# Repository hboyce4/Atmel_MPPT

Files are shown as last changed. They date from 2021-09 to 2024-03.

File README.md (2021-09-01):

# Atmel_MPPT
A Maximum Power Point Tracker converter for solar panels, running on an Atmel 8-bit MCU

Possible improvements to be made:
- Add load switch to cut power to the USB port when the battery is too low and prevent overdischarge/BMS cutout.
- Update to a 32-bit MCU.
- Change the AP3513 switching regulator IC for one with a smaller quiescent current.

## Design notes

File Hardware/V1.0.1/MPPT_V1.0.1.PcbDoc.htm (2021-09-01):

Reporting Options

# File in Previous Format

Date | : | 2021-09-01
Time | : | 19:13:26
Filename | : | C:\Users\Hugo Boyce\Documents\Electronics Projects\MPPT\Git\Atmel_MPPT\Hardware\V1.0.1\MPPT_V1.0.1.PcbDoc

Version | Warning

This file was generated by an earlier version of the software

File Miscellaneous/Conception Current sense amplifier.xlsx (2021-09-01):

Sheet: PV_Current
 |  |  |  | Editable fields in gray
Design Parameters
Vref | 4.096 | V | Max shunt voltage | 0 | V
Steps | 1024 | LSB | Min shunt voltage | -0.0512 | V
Imax | 0 | A | Peak shunt power | 0.0262144 | W
Imin | -0.512 | A |  | 26.2144 | mW
Rshunt | 0.1 | Ohms | R2/R1 | 80
 | 100 | mOhms
 |  |  | R1/(R2+R1) | 0.01234567901
 |  |  | Vref | 0 | V
 |  |  |  | 0 | mV
Composants choisis: |  |  | R1/(R2+R1), Vref | 0
R1 gain: | 1500 |  | Theoratical Formula
R2 gain: | 120000 |  |  |  |  | Formule théorique: | mA = (BIN - | 0 | ) * | 0.5
real R2/R1 | 80
R1 vref: | 1000
R2 vref: | 200000
real Vref: | 0 | V | Total range | 0.512 | A
 |  |  |  | 0.5 | mA/LSB
real max sh. V | 0 | V | Vadc @ 0A | 0 | V
real min sh. V | -0.0512 | V | LSB @ 0A | 0 | LSB
real Imax | 0 | A
real Imin | -0.512 | A | Real Formula
 |  |  | Range réel | 0.512 | A
 |  |  |  | 0.5 | mA/LSB
Low Pass Filter
Fc | 1185 | Hz | Vdc @ 0A | 0 | V
 |  |  | LSB @ 0A | 0 | LSB
C | 8.841941283e-08 | F |  |  |  | Formule théorique: | mA = (BIN - | 0 | ) * | 0.5
 | 0.08841941283 | uF
 | 88.41941283 | nF
 | 88419.41283 | pF

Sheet: Batt_Current
 |  |  |  | Editable fields in gray
Design Parameters
Vref | 4.096 | V | Max shunt voltage | 0.02048 | V
Steps | 1024 | LSB | Min shunt voltage | -0.06144 | V
Imax | 1.024 | A | Peak shunt power | 0.18874368 | W
Imin | -3.072 | A |  | 188.74368 | mW
Rshunt | 0.02 | Ohms | R2/R1 | 50
 | 20 | mOhms
 |  |  | R1/(R2+R1) | 0.01960784314
 |  |  | Vref | 0.02007843137 | V
 |  |  |  | 20.07843137 | mV
Composants choisis: |  |  | R1/(R2+R1), Vref | 0.004901960784
R1 gain: | 2000 |  | Theoratical Formula
R2 gain: | 100000 |  |  |  |  | Formule théorique: | mA = (BIN - | 256 | ) * | 4
real R2/R1 | 50
R1 vref: | 1000
R2 vref: | 200000
real Vref: | 0.02037810945 | V | Total range | 4.096 | A
 |  |  |  | 4 | mA/LSB
real max sh. V | 0.02078567164 | V | Vadc @ 0A | 1.024 | V
real min sh. V | -0.06113432836 | V | LSB @ 0A | 256 | LSB
real Imax | 1.039283582 | A
real Imin | -3.056716418 | A | Real Formula
 |  |  | Range réel | 4.096 | A
 |  |  |  | 4 | mA/LSB
Low Pass Filter
Fc | 1185 | Hz | Vdc @ 0A | 1.039283582 | V
 |  |  | LSB @ 0A | 259.8208955 | LSB
C | 6.581090474e-08 | F |  |  |  | Formule théorique: | mA = (BIN - | 260 | ) * | 4
 | 0.06581090474 | uF
 | 65.81090474 | nF
 | 65810.90474 | pF

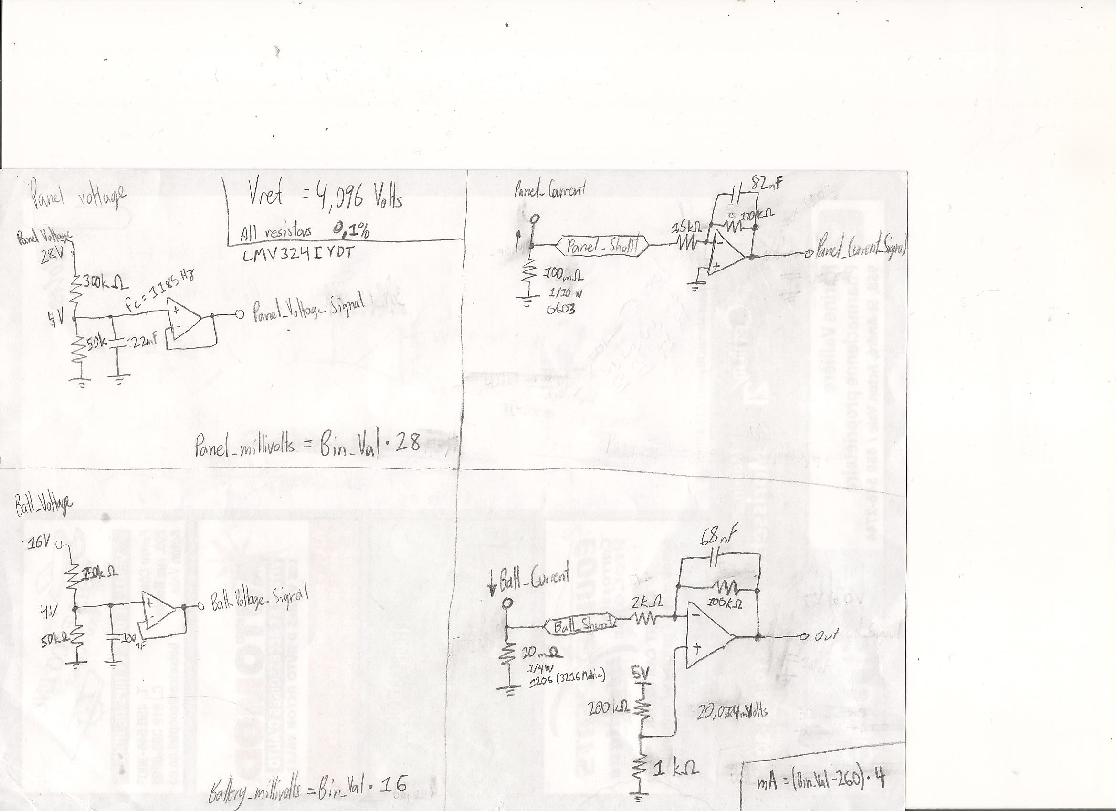
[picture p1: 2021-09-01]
Miscellaneous/MPPT_V1.0_Sense_Amplifiers.jpeg

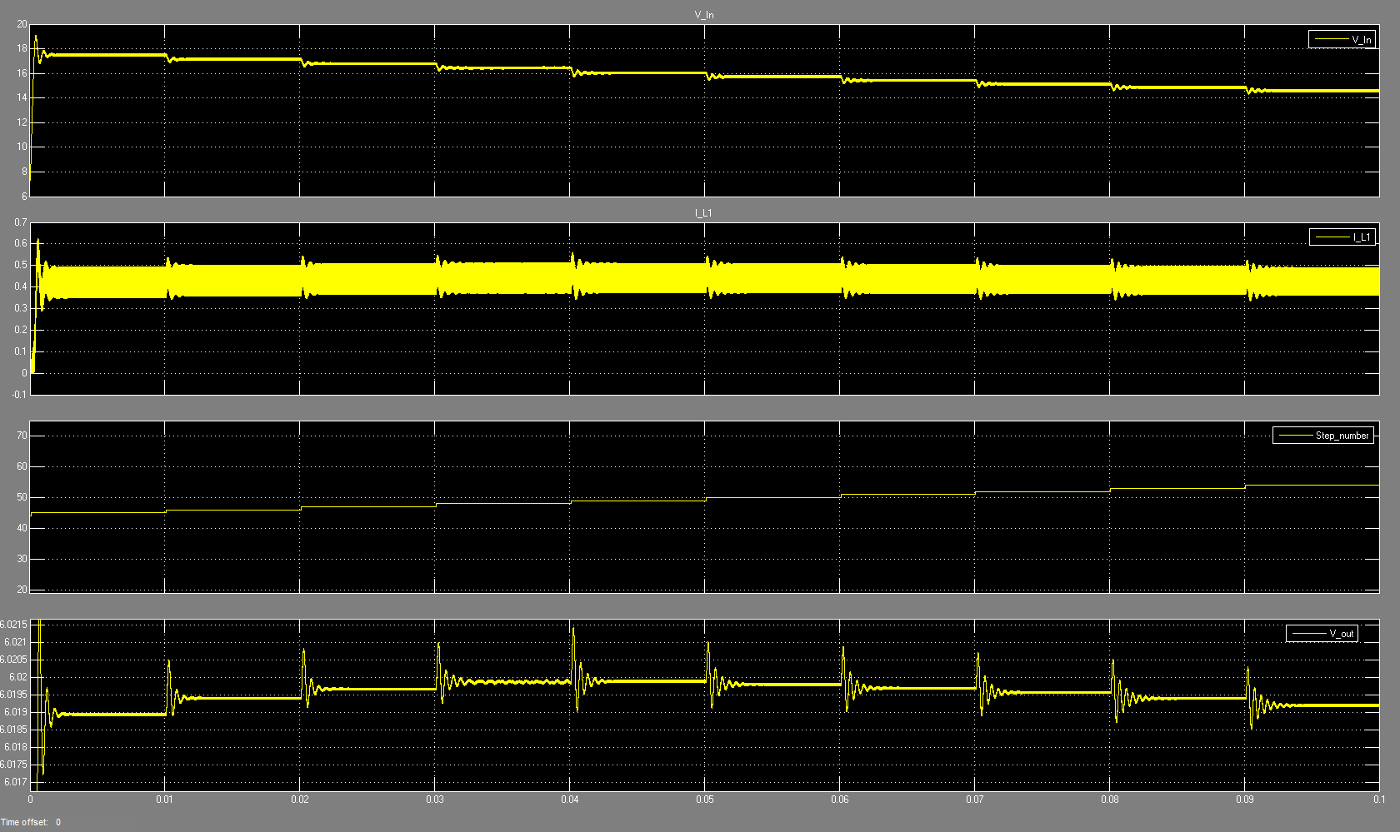
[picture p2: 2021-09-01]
Simulation/Sim Hacheur/Captures/Point optimal puissance.PNG

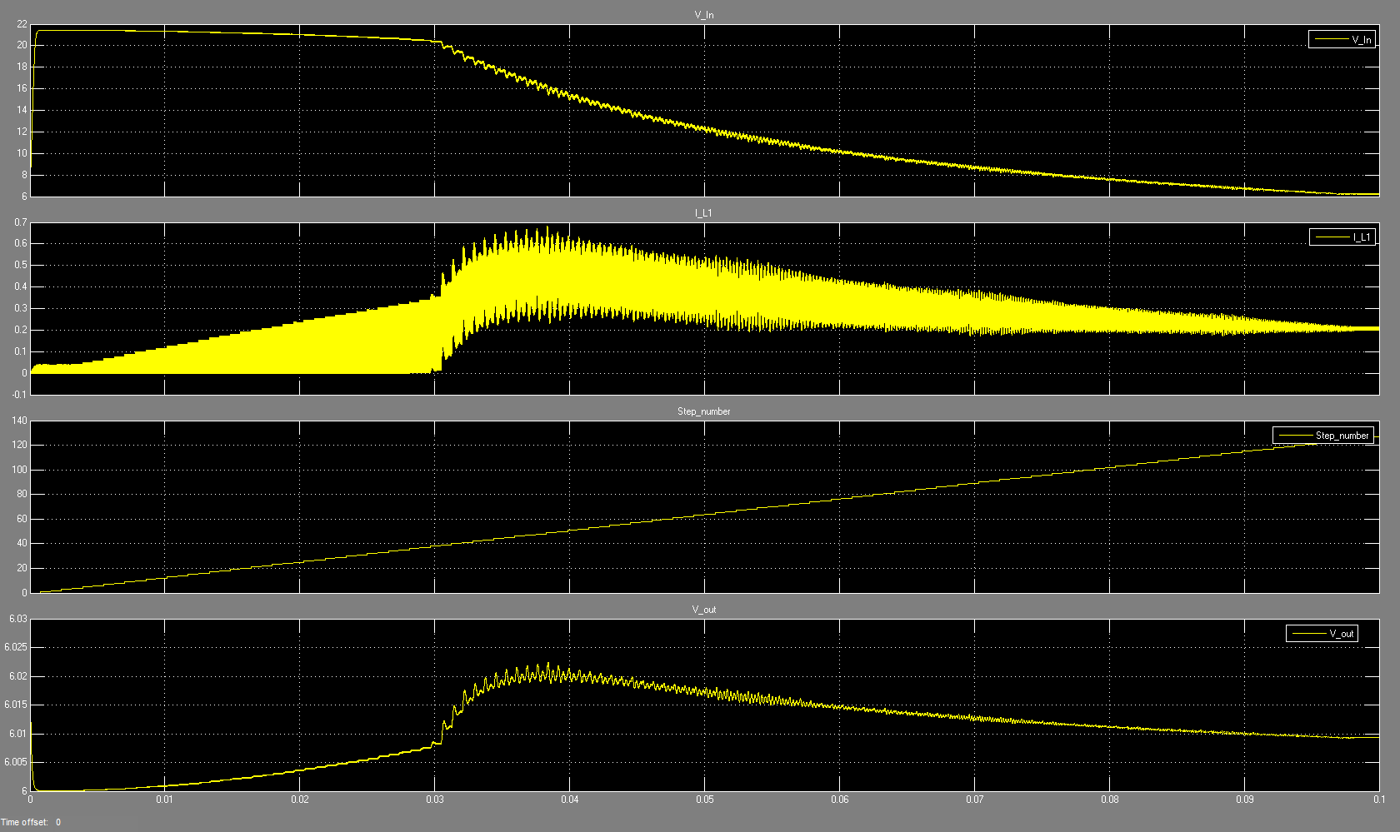
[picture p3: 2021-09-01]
Simulation/Sim Hacheur/Captures/100uH.PNG

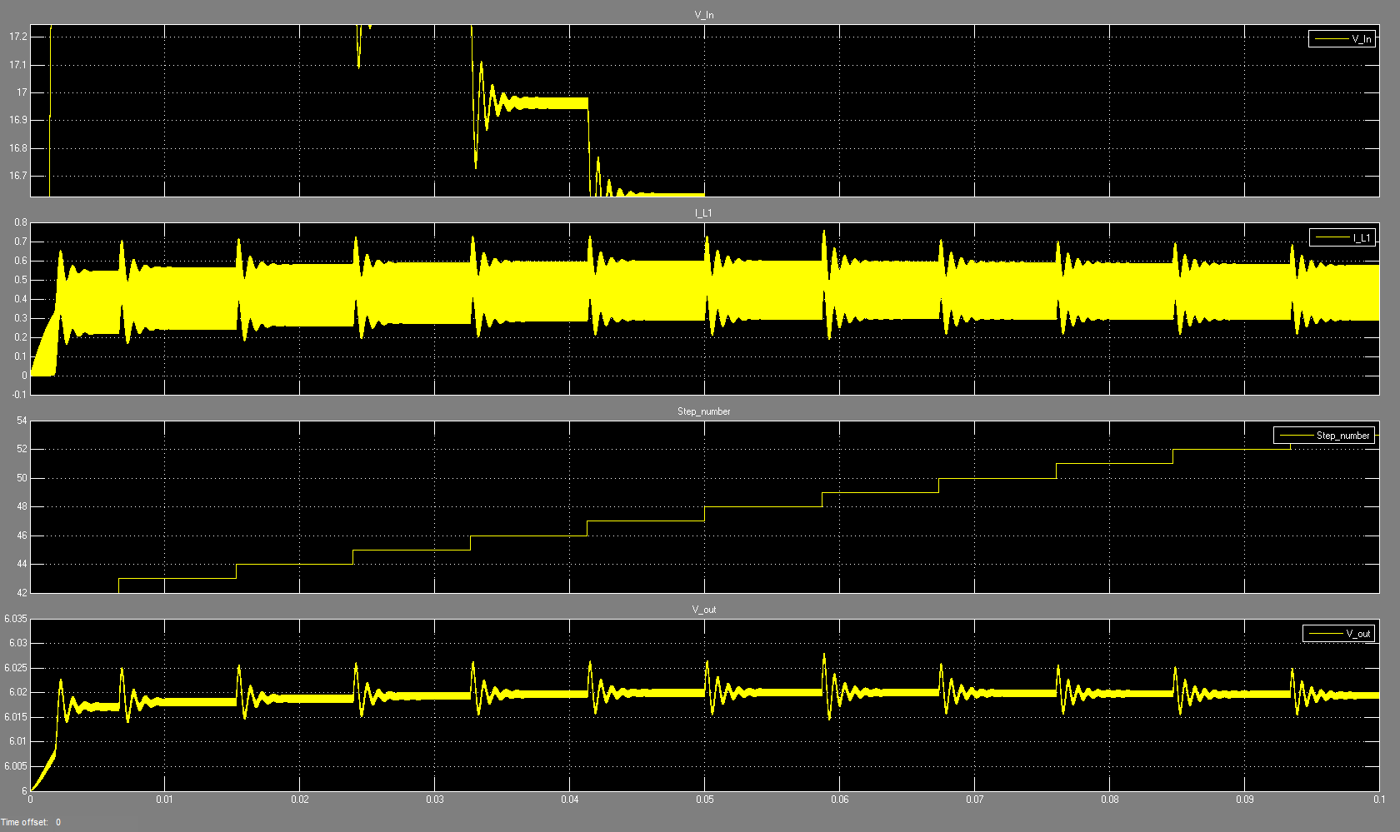
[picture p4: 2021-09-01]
Simulation/Sim Hacheur/Captures/HAcheur, 100uH, 22uF, 220uF.PNG

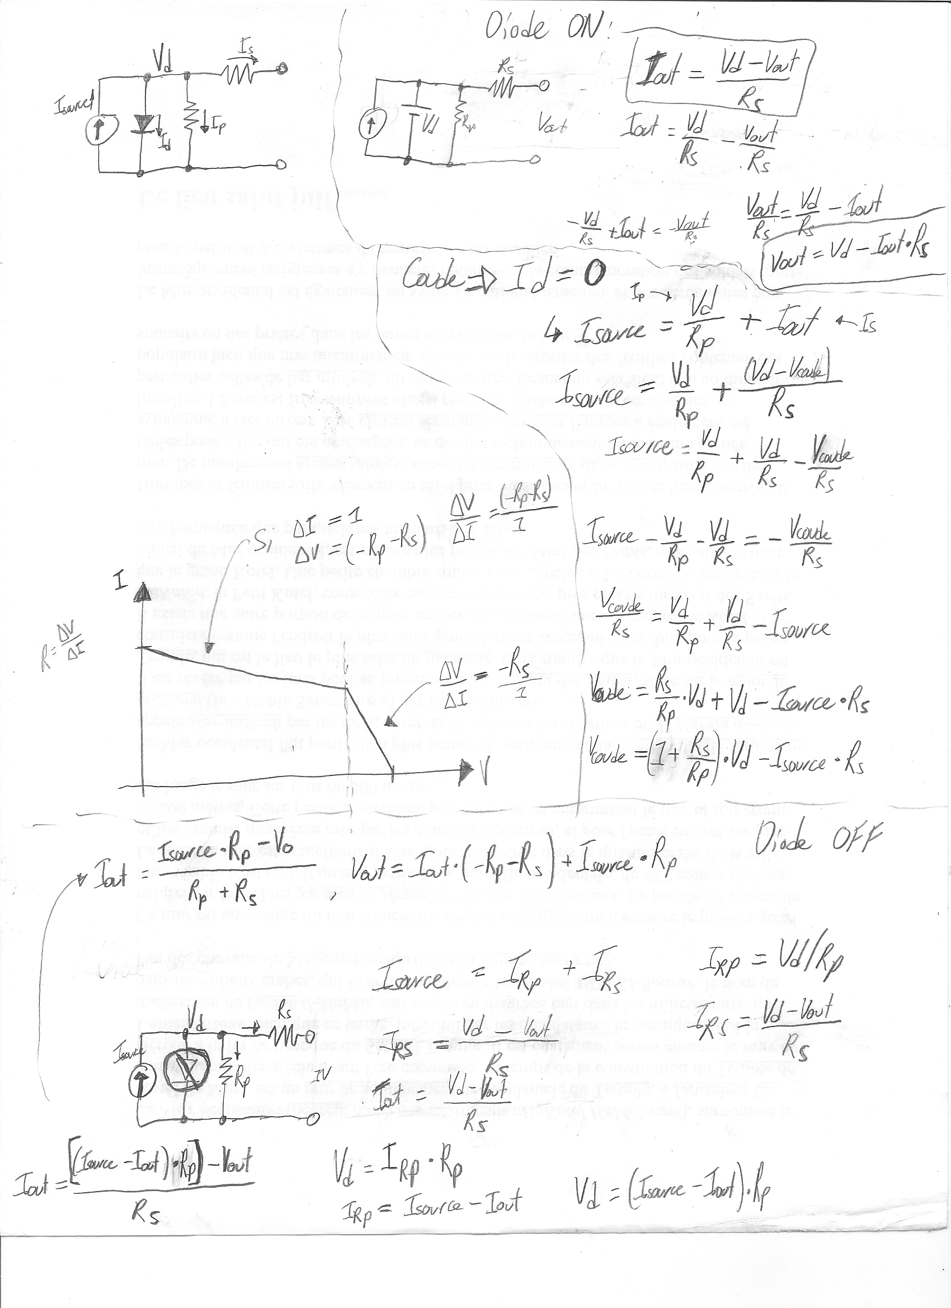
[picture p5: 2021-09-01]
Miscellaneous/Approx linéaires PV cell 001.bmp

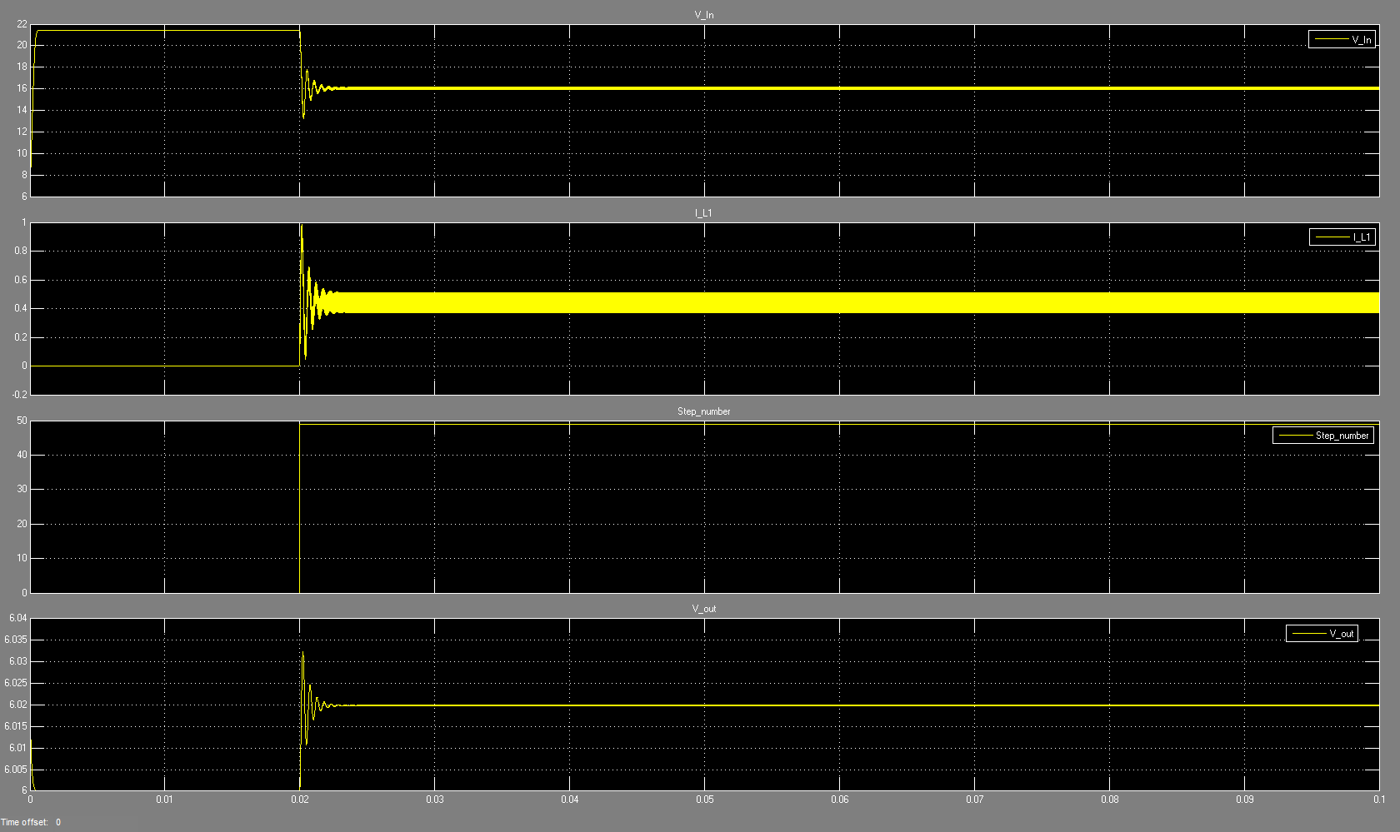
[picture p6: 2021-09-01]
Simulation/Sim Hacheur/Captures/Temps stabilisation, no-power to max power.PNG

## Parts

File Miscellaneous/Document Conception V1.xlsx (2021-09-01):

BOM
Digikey P/N | Manuf. P/N | Comment | Qty | URL
AP3513EMPTR-G1DICT-ND | AP3513EMPTR-G1 | Buck converter IC | 1 | http://www.digikey.ca/product-detail/en/diodes-incorporated/AP3513EMPTR-G1/AP3513EMPTR-G1DICT-ND/4505181
RLB0912-4R7ML-ND | RLB0912-4R7ML | Inductor | 1 | http://www.digikey.ca/products/en/inductors-coils-chokes/fixed-inductors/71?k=RLB0912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
 | AIAP-03-101 | Inductor | 1
 | BUK9M53-60E | N_mosfet | 1
732-8602-1-ND (https://www.digikey.ca/product-detail/en/wurth-electronics-inc/860010373010/732-8602-1-ND/5728559) | 860010373010 (https://www.digikey.ca/product-detail/en/wurth-electronics-inc/860010373010/732-8602-1-ND/5728559) | 220uF electrolytic cap | 1 | https://www.digikey.ca/product-detail/en/wurth-electronics-inc/860010373010/732-8602-1-ND/5728559
 | ATMEGA16A-AU | Microcontrôleur Atmel | 1
497-4943-1-ND (https://www.digikey.ca/product-detail/en/stmicroelectronics/LMV324IDT/497-4943-1-ND/1003414) | LMV324IDT (https://www.digikey.ca/product-detail/en/stmicroelectronics/LMV324LIDT/497-13052-1-ND/3458219) | Quad rail-to-rail op amp | 1 | https://www.digikey.ca/product-detail/en/stmicroelectronics/LMV324IDT/497-4943-1-ND/1003414
ISL6208CBZ-ND (https://www.digikey.ca/product-detail/en/intersil/ISL6208CBZ/ISL6208CBZ-ND/1063886) | ISL6208CBZ (https://www.digikey.ca/product-detail/en/intersil/ISL6208CBZ/ISL6208CBZ-ND/1063886) | Mosfet driver IC | 1 | https://www.digikey.ca/product-detail/en/intersil/ISL6208CBZ/ISL6208CBZ-ND/1063886

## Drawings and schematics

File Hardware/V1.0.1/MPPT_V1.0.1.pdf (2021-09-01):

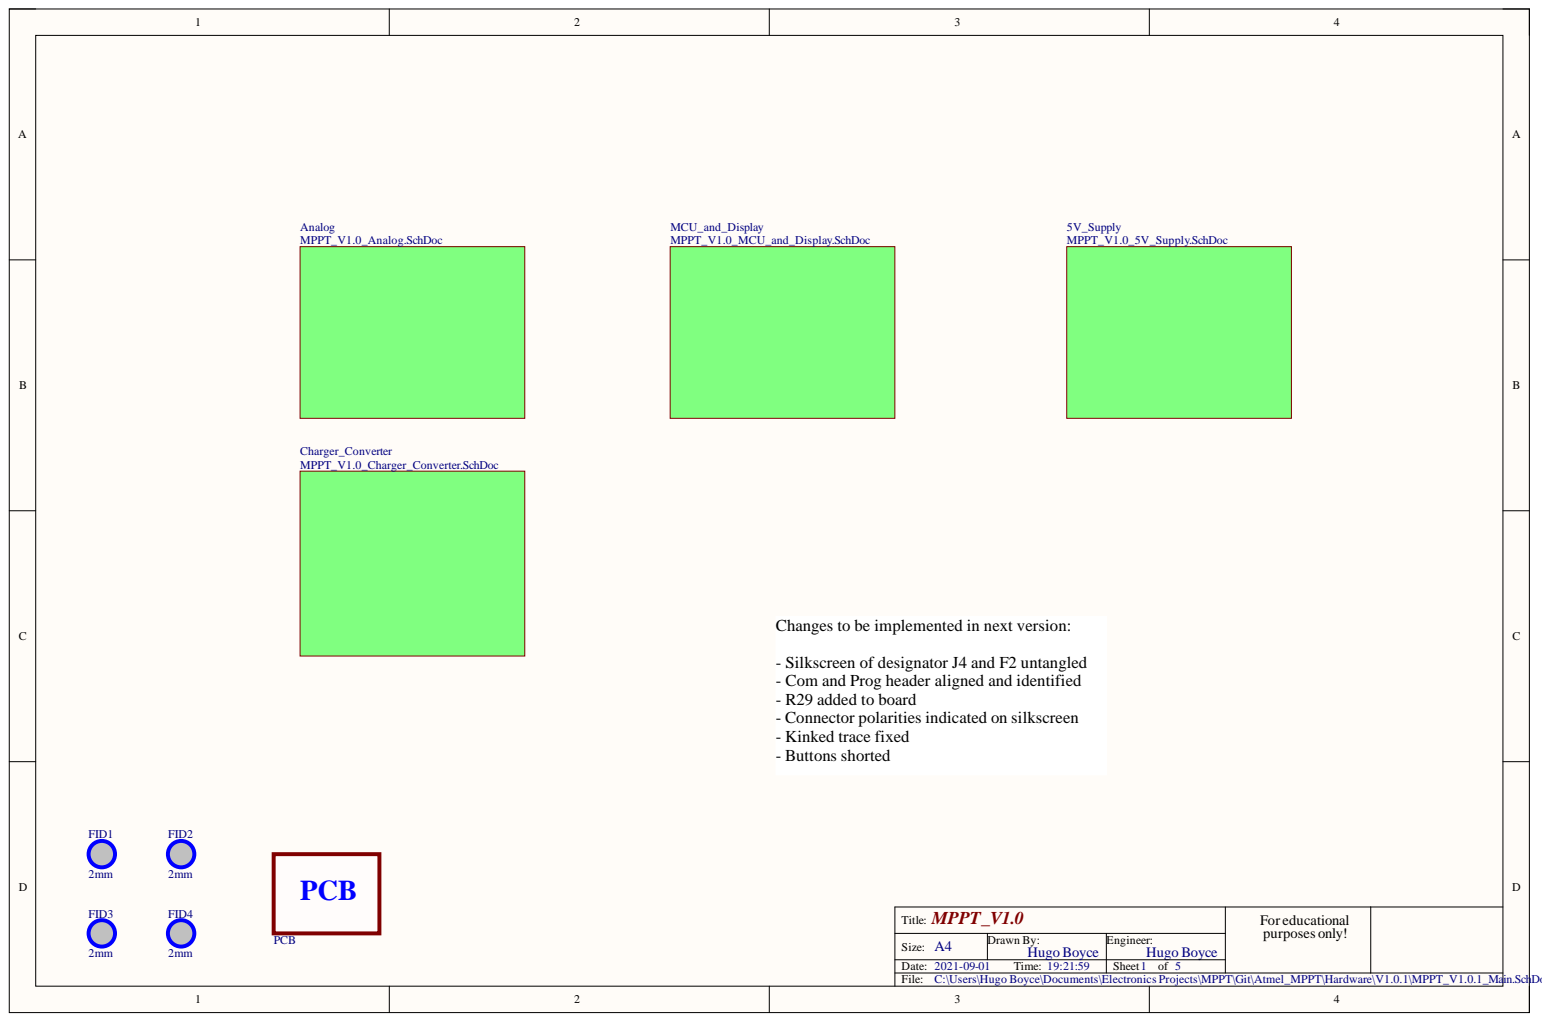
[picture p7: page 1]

Changes to be implemented in next version:

- Silkscreen of designator J4 and F2 untangled
- Com and Prog header aligned and identified
- R29 added to board
- Connector polarities indicated on silkscreen
- Kinked trace fixed
- Buttons shorted

MPPT_V1.0
Title:
Date:
C:\Users\Hugo Boyce\Documents\Electronics Projects\MPPT\Git\Atmel_MPPT\Hardware\V1.0.1\MPPT_V1.0.1_Main.SchDoc

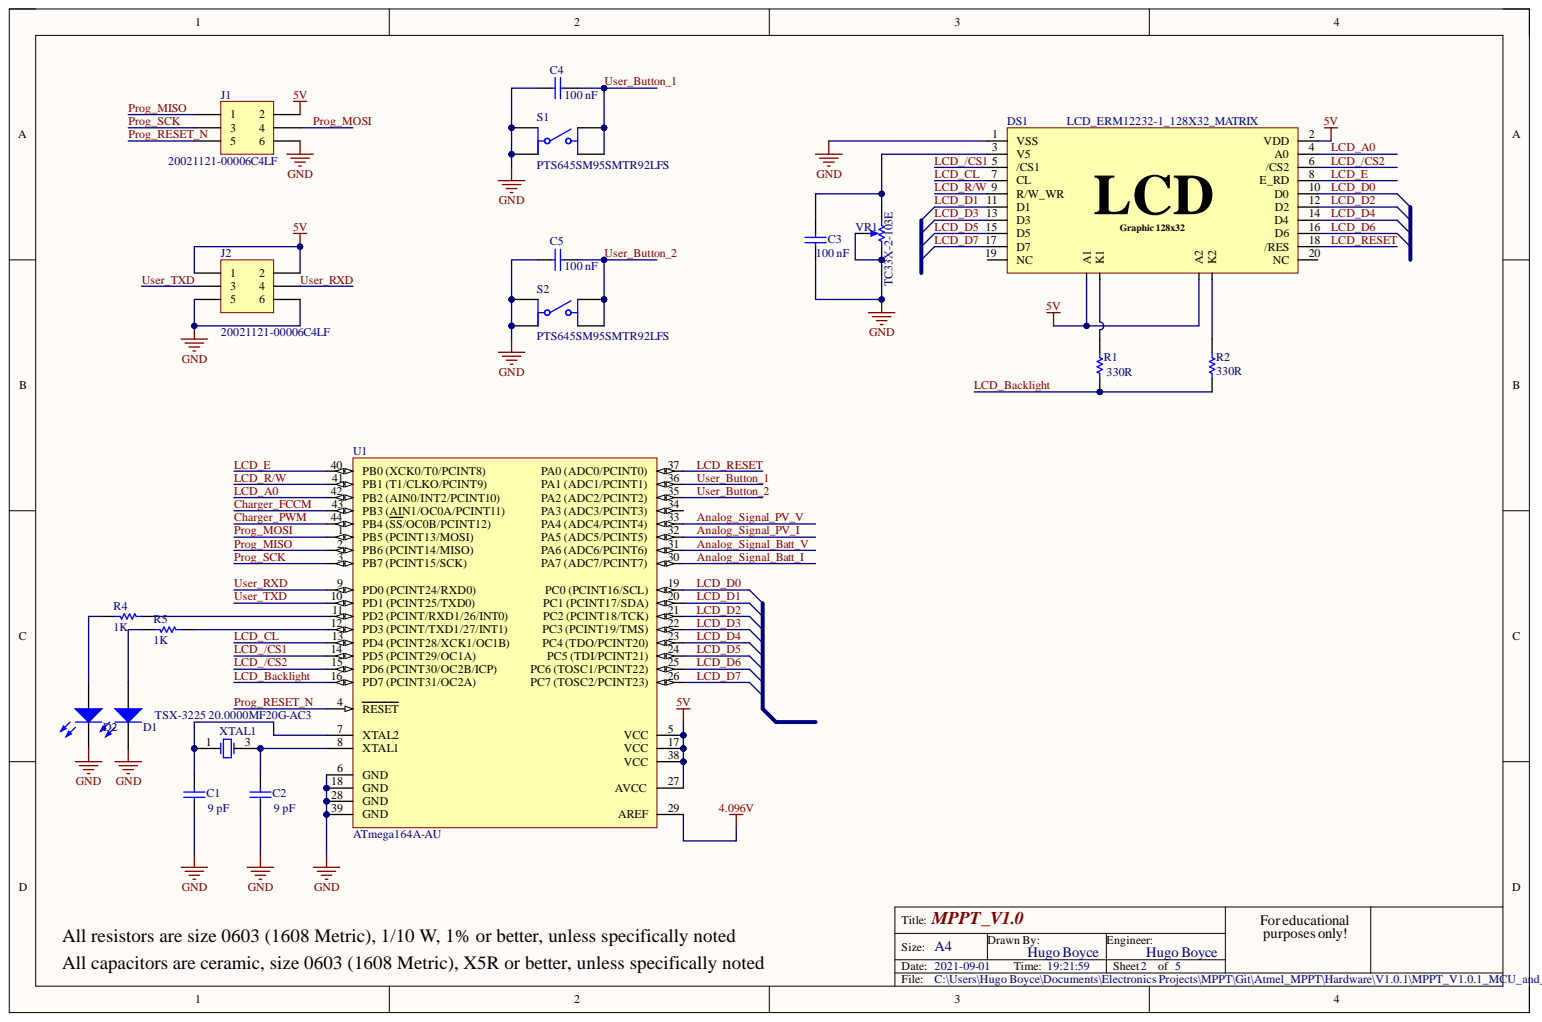
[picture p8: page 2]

All resistors are size 0
All capacitors are ceramic, size 0

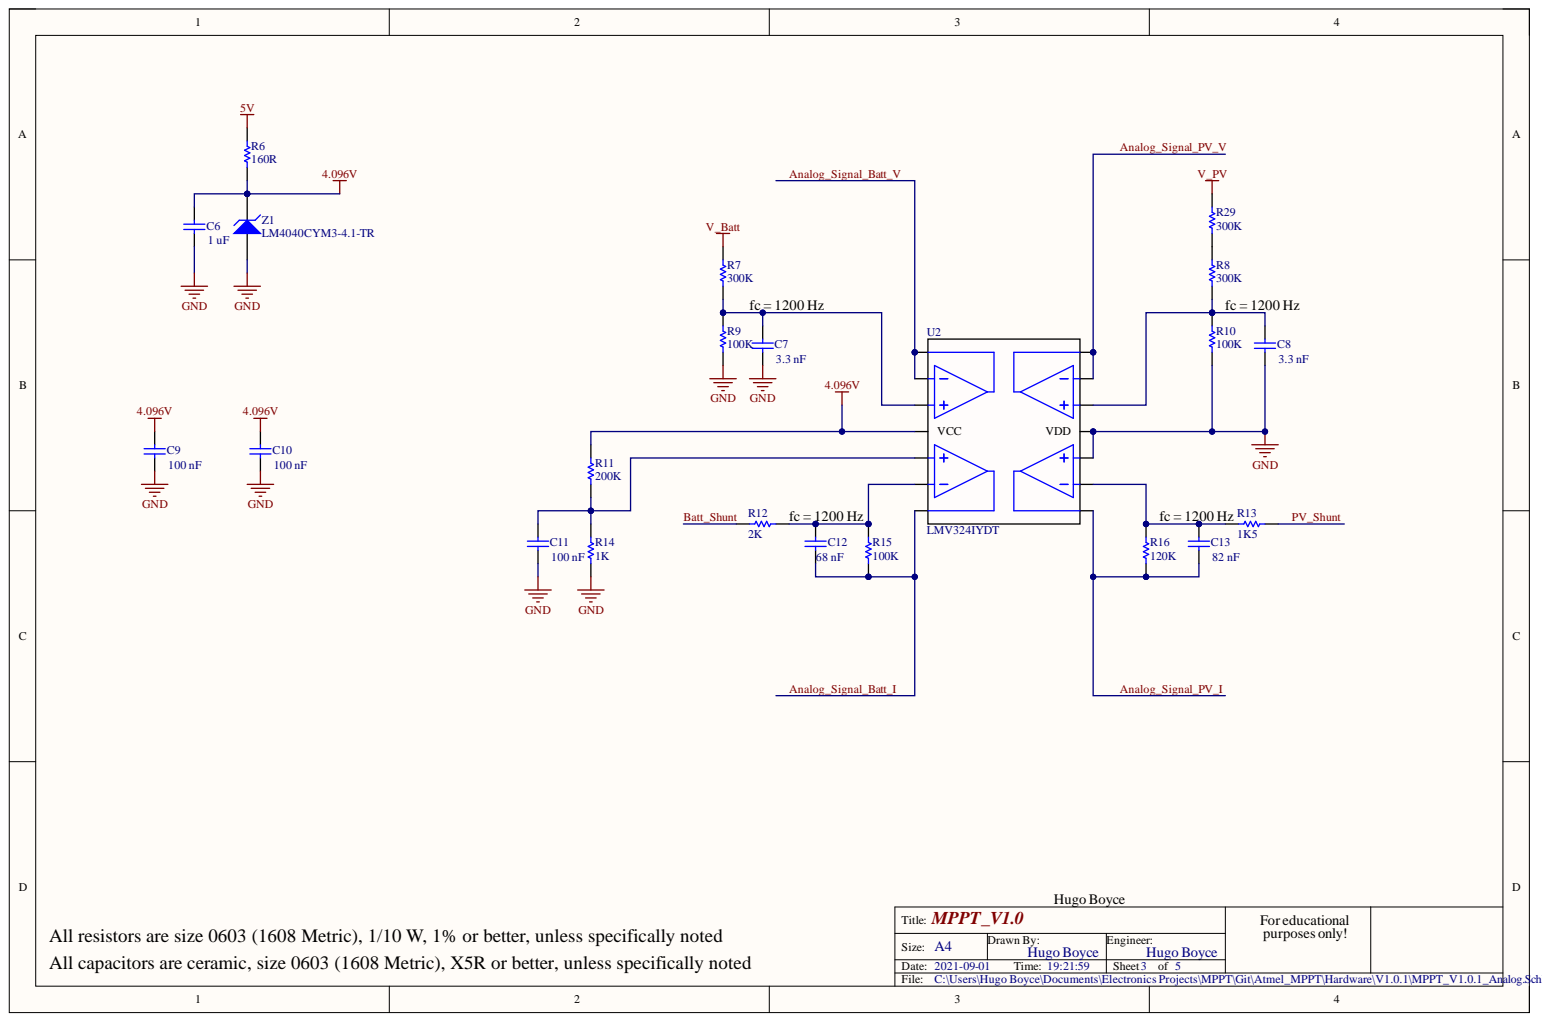
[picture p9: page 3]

All resistors are size 0
All capacitors are ceramic, size 0

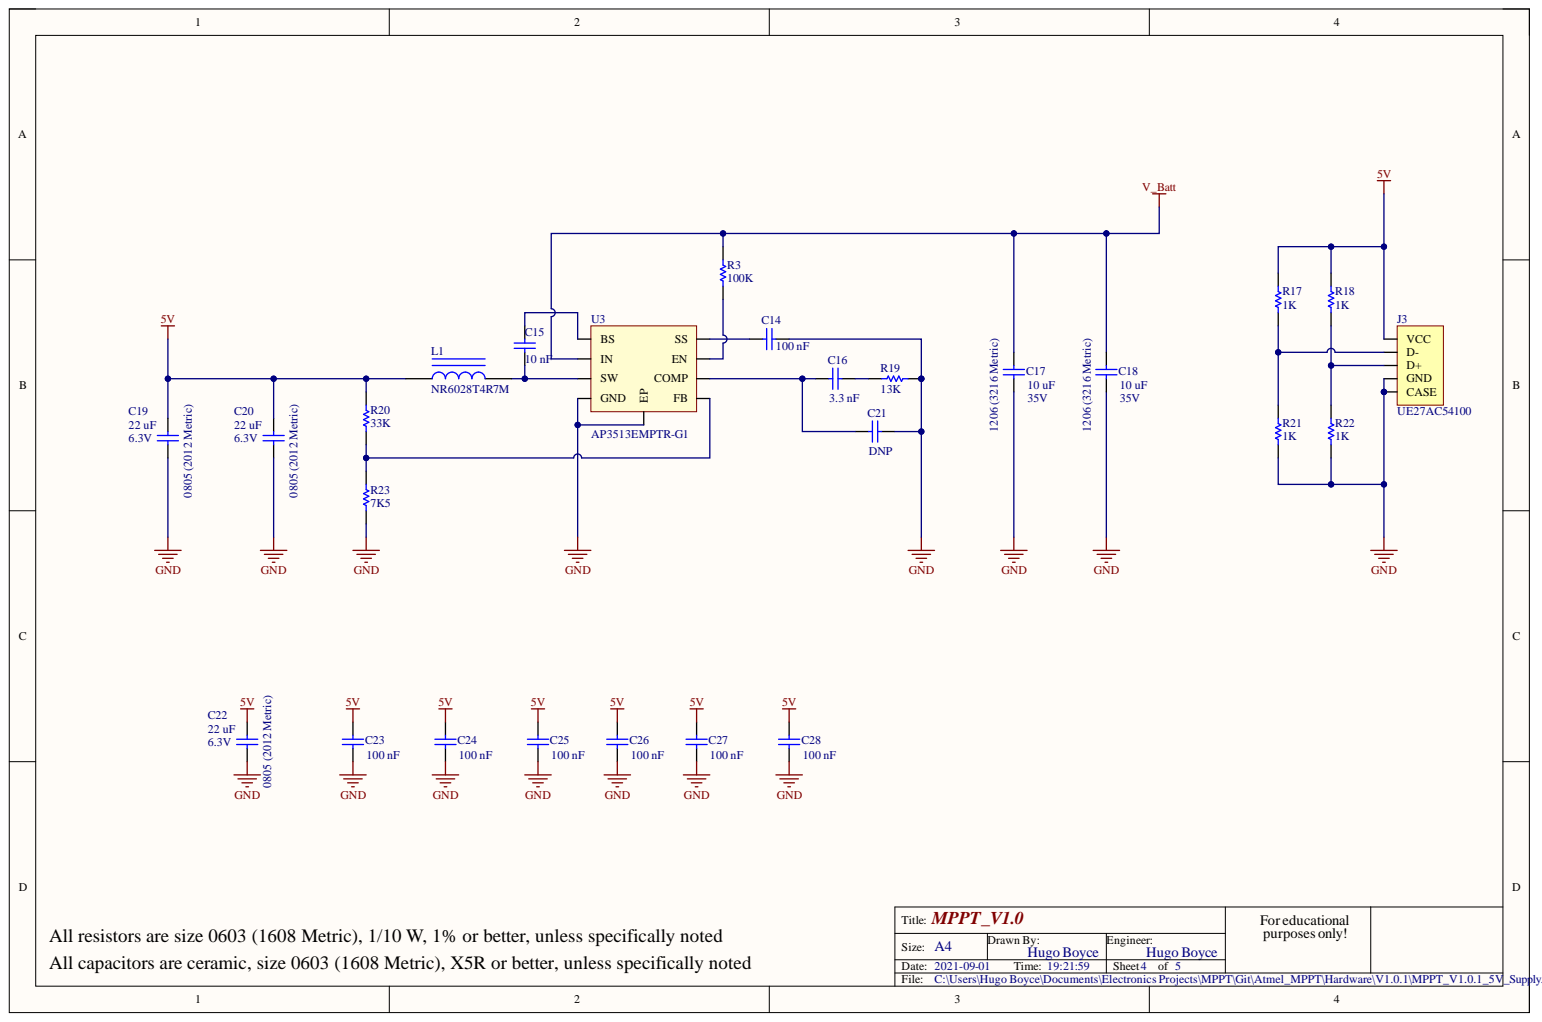
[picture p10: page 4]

IN COMP EN SWGND FB | C1 6

All resistors are size 0
All capacitors are ceramic, size 0

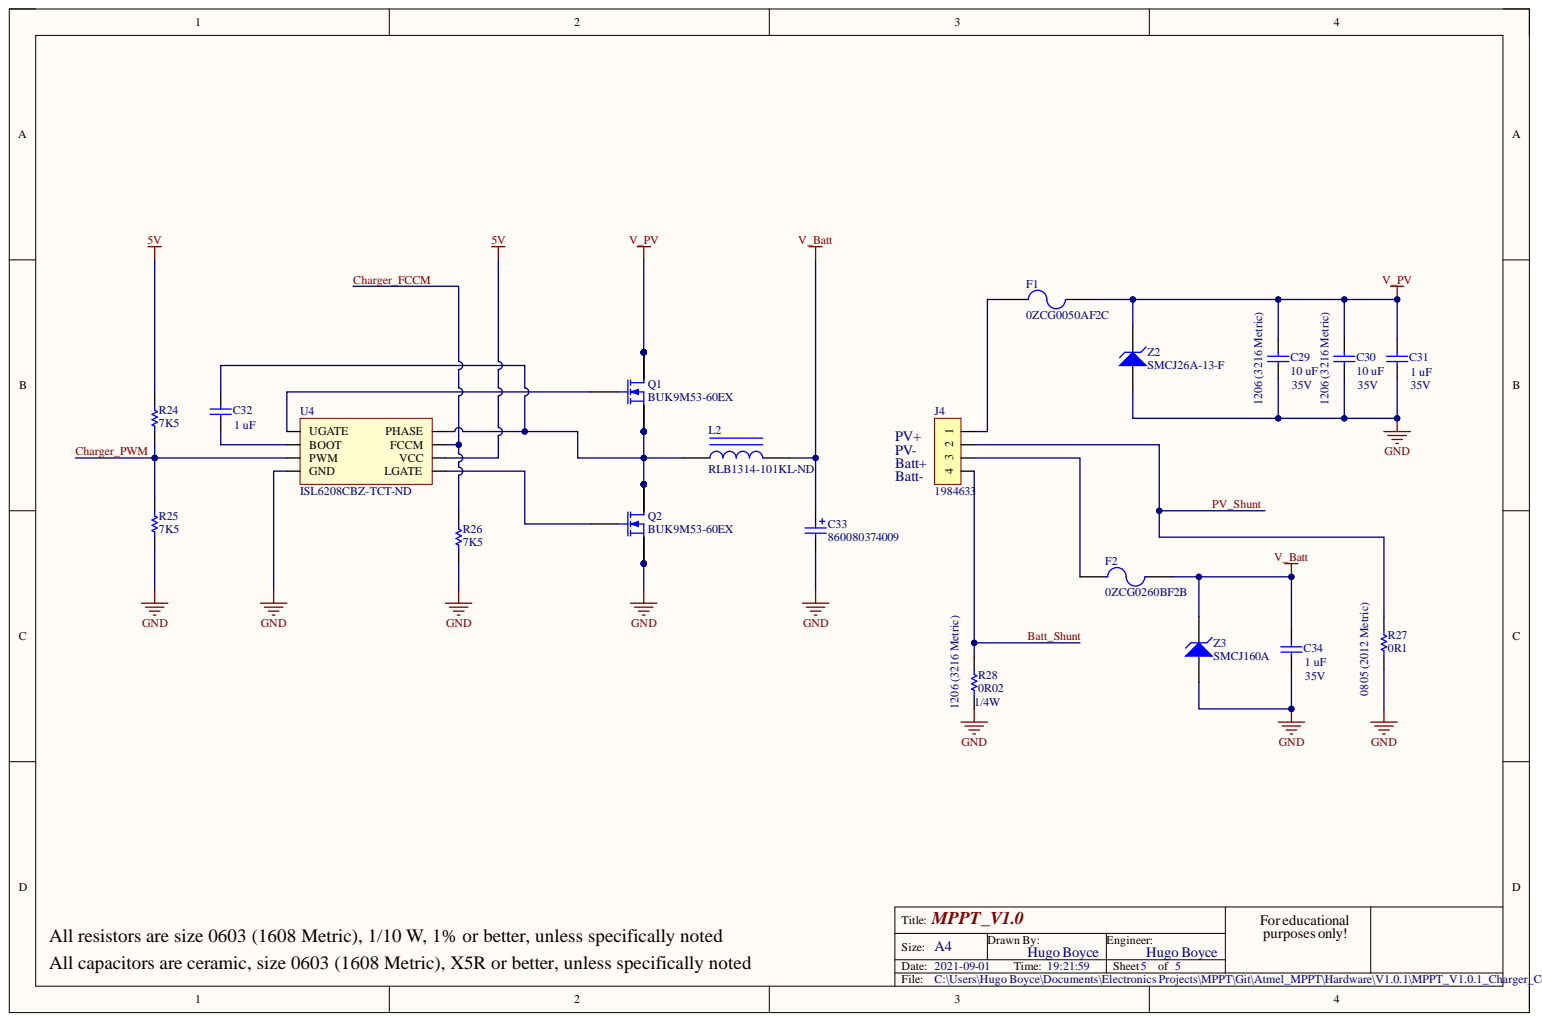
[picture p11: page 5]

All resistors are size 0
All capacitors are ceramic, size 0

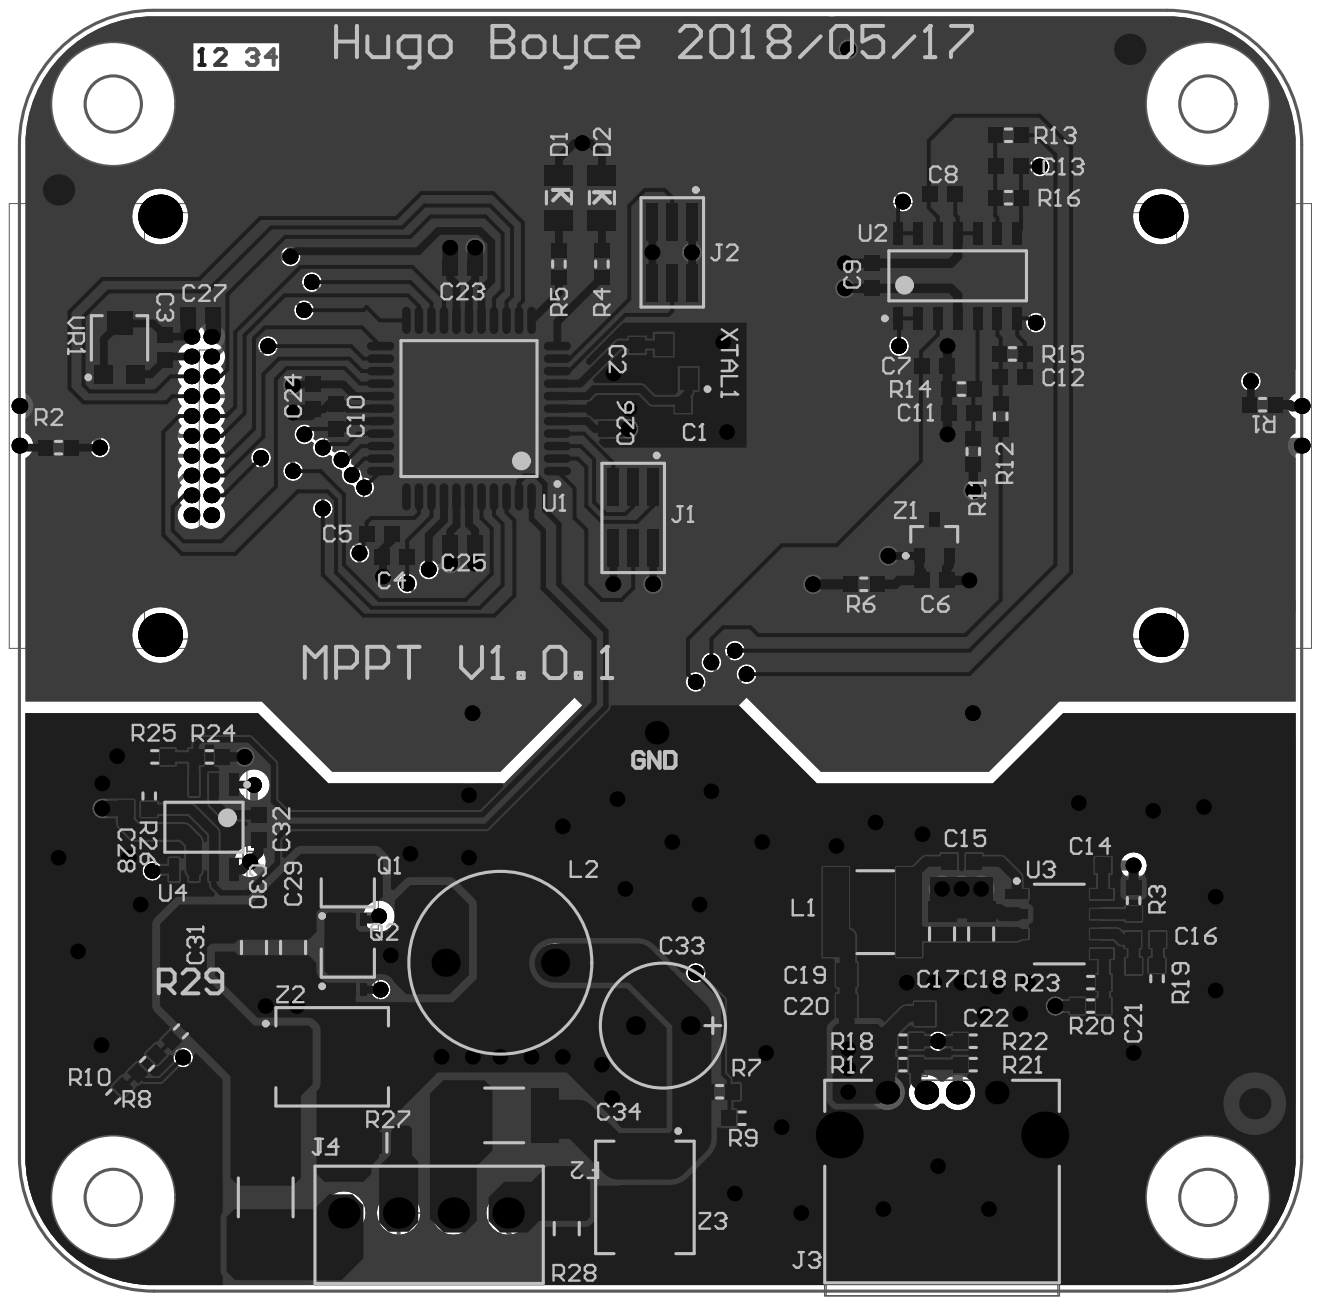
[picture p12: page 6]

Comment | Description | Designator | Footprint | Quantity | Value
UE27AC54100 | CONN RCPT USB TYPE A R/A GOLD | J3 | UE27AC5410 | 1
TSX-3225 20.0000MF20G-AC3 | CRYSTAL 20.0000MHZ 9PF SMD | XTAL1 | EPSON_TSX-3225 | 1
TC33X-2-103E | TRIMMER 10K OHM 0.1W SMD | VR1 | TC33_BOURNS | 1
SMCJ160A | TVS DIODE 160VWM 259VC SMC | Z3 | SMCJxxx | 1
SMCJ26A-13-F | TVS DIODE 26VWM 42.1VC SMC | Z2 | SMCJxxx | 1
RLB1314-101KL | FIXED IND 100UH 1A 120 MOHM TH | L2 | BOURNS_RLB1314 | 1
Res SMD | Resistor | R1, R2 | RESC1608N | 2 330R
Res SMD | Resistor | R3, R9, R10, R15 | RESC1608N | 4 100K
Res SMD | Resistor | R4, R5, R14, R17, R18, R21, R22 | RESC1608N | 7 1K
Res SMD | Resistor | R6 | RESC1608N | 1 160R
Res SMD | Resistor | R7, R8, R29 | RESC1608N | 3 300K
Res SMD | Resistor | R11 | RESC1608N | 1 200K
Res SMD | Resistor | R12 | RESC1608N | 1 2K
Res SMD | Resistor | R13 | RESC1608N | 1 1K5
Res SMD | Resistor | R16 | RESC1608N | 1 120K
Res SMD | Resistor | R19 | RESC1608N | 1 13K
Res SMD | Resistor | R20 | RESC1608N | 1 33K
Res SMD | Resistor | R23, R24, R25, R26 | RESC1608N | 4 7K5
Res SMD | Resistor | R27 | RESC2012N | 1 0R1
Res SMD | Resistor | R28 | RESC3216N | 1 0R02
PTS645SM95SMTR92LFS | SWITCH TACTILE SPST-NO 0.05A 12V | S1, S2 | PTS645SM95SMTR92LFS | 2
PCB | Printed Circuit Board | PCB | | 1
NR6028T4R7M | FIXED IND 4.7UH 3A 40.3 MOHM SMD | L1 | NR6028 | 1
LMV324IYDT | IC OPAMP GP 1.3MHZ RRO 14SO | U2 | LMV324IYDT | 1
LM4040CYM3-4.1-TR | IC VREF SHUNT 4.096V SOT23 | Z1 | LM4040C | 1
LCD_ERM12232-1_128X32_MATRIX | 128x64 Graphic LCD Module, EastRising | DS1 | LCD_ERM12232 | 1
ISL6208CBZ-T | IC MOSFET DRVR SYNC BUCK 8-SOIC | U4 | ISL6208CBZ-T | 1
1608 | Capacitor | C15 | CAPC1608N | 1 10 nF
Cap SMD | Capacitor | C1, C2 | CAPC1608N | 2 9 pF
Cap SMD | Capacitor | C3, C4, C5, C9, C10, C11, C14, C23, C24, C25, C26, C27, C28 | CAPC1608N | 13 100 nF
Cap SMD | Capacitor | C6, C31, C32, C34 | CAPC1608N | 4 1 uF
Cap SMD | Capacitor | C7, C8, C16 | CAPC1608N | 3 3.3 nF
Cap SMD | Capacitor | C12 | CAPC1608N | 1 68 nF
Cap SMD | Capacitor | C13 | CAPC1608N | 1 82 nF
Cap SMD | Capacitor | C17, C18, C29, C30 | CAPC3216N | 4 10 uF
Cap SMD | Capacitor | C21 | CAPC1608N | 1 DNP
JMK212BBJ226MGHT | Capacitor | C19, C20, C22 | CAPC2012N | 3 22 uF
BUK9M53-60EX | MOSFET N-CH 60V 17A LFPAK | Q1, Q2 | BUK9M53-60E | 2
ATmega164A-AU | 8-bit AVR Microcontroller, 16KB Flash, 512 Bytes EEPROM, 1KB SRAM, 44-pin TQFP, Industrial Grade (-40°C to 85°C) | U1 | 44A_N | 1
AP3513EMPTR-G1 | IC REG BUCK ADJ 3A SYNC 8SOIC | U3 | AP3513E | 1
860080374009 | CAP ALUM 220UF 20% 16V THRU HOLE | C33 | 860080374009 | 1
20021121-00006C4LF | CONN HEADER 6POS DL UNSHRD SMD | J1, J2 | 20021121-00006 | 2
1984633 | CONN TERM BLOCK T/H 4POS 3.5MM | J4 | 1984633 | 1
150120RS75000 | LED RED CLEAR 1206 SMD | D1, D2 | 150120RS75000 | 2
0ZCG0260BF2B | PTC RESET FUSE 16V 2.6A 1812 | F2 | OZCG0_BEL_FUSE | 1
0ZCG0050AF2C | PTC RESET FUSE 30V 500MA 1812 | F1 | OZCG0_BEL_FUSE | 1

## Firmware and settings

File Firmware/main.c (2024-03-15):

/*
 * MPPT_V0.9.7
 *
 * Created: 2020-08-25
 * Author : Hugo Boyce
 */ 

#include <avr/io.h>
#include <avr/pgmspace.h>
#include <stdbool.h>
#include <stdlib.h>
#include <avr/interrupt.h>

#ifndef F_CPU
#define F_CPU 20000000U
#endif
#include <util/delay.h>



#include "Buttons_and_LEDs.h"
#include "Analog.h"
#include "System.h"
#include "Display.h"
#include "Logging.h"



volatile ADC_Data_t ADC_Data = {0};	/* ADC data must be global and volatile. All initialized to zero */
volatile Analog_Data_t Current_Analog_Data = {0};
volatile Logging_Data_t Current_Logging_Data;
volatile Scan_Data_t Current_Scan_Data = {.Enable_Scan = true, .Scan_Countdown = SCAN_DIVIDER};
volatile Battery_Data_t Battery_Voltage_Limits = {0};

volatile Converter_User_Required_State_t Converter_User_Required_State;
volatile Button_Event_t Last_Button_Event = NO_BUTTON_PRESS;

int main(void)
{
	Timers_Init();
	Display_Init();
	Buttons_LEDs_Init();
	ADC_Init();
	Logging_Fetch_Log(&Current_Logging_Data);

	sei();	
	

	_delay_ms(10);
	uint8_t battery_type = Buttons_Get_State();
	Battery_Set_Limits(battery_type, &Battery_Voltage_Limits);
	Display_Battery_Type(battery_type);


	
    while (1) 
    {
		Logging_Save_Log(&Current_Logging_Data);
		
		Buttons_Watch_for_Event(&Last_Button_Event);
		
		Converter_Modify_State(&Last_Button_Event, &Converter_User_Required_State, &Current_Scan_Data);

		Display_P_I_V_Conv_State(&Current_Analog_Data, Current_Logging_Data.Peak_PV_P, Converter_Get_State(),OCR0B, Converter_User_Required_State);
		
		_delay_ms(10);
    }
}

ISR(TIMER2_OVF_vect, ISR_NOBLOCK){	/* Nested interrupts. Runs at 76.2939 Hz */
	
	ADC_Get_Analog_Data(&Current_Analog_Data, &Battery_Voltage_Limits); /* Refresh analog data*/
	
	Analog_Calc_Avg(&Current_Analog_Data);	
	
	Logging_Monitor_Values(&Current_Analog_Data, &Current_Logging_Data);
	
	Converter_Main(&Converter_User_Required_State, &Current_Analog_Data, &Current_Scan_Data);
	
}

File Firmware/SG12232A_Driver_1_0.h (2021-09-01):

/*********************************************************************************
   DRIVER FOR 122x32 SG12232A graphics LCD FROM altronics.com.au
   Using the SED1520 chipset

   Ver 1.0 - Apr 09 - Original version

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
   For more details and programming notes go to http://geoffg.net/SG12232A
   
   This code is derived from code for the SED1520 by Radoslaw Kwiecien (en.radzio.dxp.pl)

   Target/Development environment:
    - Microchip PIC microcontroller chips
    - Microchip MPLAB V8 or later
    - CCS C Compiler V4 or later (tested)
    - HiTech C Compiler (not tested)
    
************************************************************************************
    
   This driver exposes the following functions and defines.

   glcd_init()
      * Initialises the display
      * Must be called before any other function.

   glcd_pixel(x,y,colour)
      * Sets the pixel to the given colour.
        - origin (x=0, y=0) is top left corner
        - colour can be ON or OFF (0 or 1)

   glcd_fillScreen(colour)
      * Fills the entire LCD with the given colour.
        - colour can be ON or OFF (0 or 1)

   GLCD_GRAPHICS_WIDTH = 122     Width of display
   GLCD_GRAPHICS_HEIGHT = 32     Height of display

************************************************************************************

    The following pins must be defined */


#ifndef SG12232A_DRIVER_1_0_H_
#define SG12232A_DRIVER_1_0_H_


 #include <stdint.h>
 #include <avr/io.h>
 #include <stdlib.h>
 #include <avr/pgmspace.h>
 
 #ifndef F_CPU
 #define F_CPU 20000000U
 #endif
 #include <util/delay.h>
    
#define SED1520_DATA_PORT 	PORTC
#define SED1520_DATA_DDR 	DDRC
#define SED1520_DATA_PORT_IN 	PINC

#define SED1520_CONTROL_CS_PORT 	PORTD
#define SED1520_CONTROL_CS_DDR 		DDRD
#define SED1520_CS1		(1 << PD5)	// Actif bas
#define SED1520_CS2		(1 << PD6)	// Actif bas

#define SED1520_CONTROL_RESET_PORT 	PORTA
#define SED1520_CONTROL_RESET_DDR 	DDRA
#define SED1520_RES		(1 << PA0)

#define SED1520_CONTROL_OTHER_PORT 	PORTB
#define SED1520_CONTROL_OTHER_DDR 	DDRB
#define SED1520_E		(1 << PB0)
#define SED1520_RW		(1 << PB1)
#define SED1520_A0		(1 << PB2)

#define SED1520_CLK_DDR		DDRD
#define SED1520_CLK_PIN		(1 << PD4)

 

/************************************************************************************/

#define DISPLAY_ON 0xAF
#define DISPLAY_OFF 0xAE
#define DISPLAY_START_LINE 0xC0
#define PAGE_ADDRESS_SET 0xB8
#define COLUMN_ADDRESS_SET 0x00
#define ADC_CLOCKWISE 0xA0
#define ADC_COUNTERCLOCKWISE 0xA1
#define STATIC_DRIVE_ON 0xA5
#define STATIC_DRIVE_OFF 0xA4
#define DUTY_RATIO_16 0xA8
#define DUTY_RATIO_32 0xA9
#define READ_MODIFY_WRITE 0xE0
#define END_READ_MODIFY 0xEE
#define RESET 0xE2

#define SCREEN_WIDTH    122
#define SCREEN_HEIGHT 32

void glcd_init(void);
/* Initialises the display
* Must be called before any other function. */

void glcd_pixel(uint8_t x, uint8_t y, uint8_t colour);
/* Sets the pixel to the given colour.
- origin (x=0, y=0) is top left corner
- colour can be ON or OFF (0 or 1) */

void glcd_fillScreen(uint8_t colour);
/* Fills the entire LCD with the given colour.
- colour can be ON or OFF (0 or 1) */


void glcd_WaitForStatus(uint8_t status, uint8_t chip);
void glcd_WriteCommand(uint8_t commandToWrite, uint8_t chip);
void glcd_goto(uint8_t x, uint8_t y);
void glcd_WriteData_XY(uint8_t x, uint8_t y, uint8_t dataToWrite);
void glcd_WriteData_Bulk(uint8_t dataToWrite);
uint8_t glcd_ReadData(uint8_t x, uint8_t y);
void glcd_WriteChar(uint8_t* x_pos, uint8_t* y_pos, char x);
void glcd_WriteString(uint8_t* x_pos, uint8_t* y_pos, char * string);
void glcd_WriteString_P(uint8_t* x_pos, uint8_t* y_pos, const char * string);

#endif

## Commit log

2021-09-01 Files added at FW version 0.9.7 and HW version 1.0.1
    Initial file add
    [Caractérisation Panneau 1.xlsx, Conception Current sense amplifier.xlsx, Document Conception V1.xlsx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]
2021-09-01 Exported .pdf
    [MPPT_V1.0.1.PrjPcb, MPPT_V1.0.1_Main.SchDoc]
2024-06-16 Changed voltage limit for 3S battery to 12300mV and 12000mV

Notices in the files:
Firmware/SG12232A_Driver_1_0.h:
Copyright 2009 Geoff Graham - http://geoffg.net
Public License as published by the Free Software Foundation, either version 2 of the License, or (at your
